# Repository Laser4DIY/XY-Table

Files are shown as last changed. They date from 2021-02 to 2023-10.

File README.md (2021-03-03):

# LASER4DIY Low Profile XY Table

XY table to be used for the Laser4DIY project, see http://www.laser4diy.org/

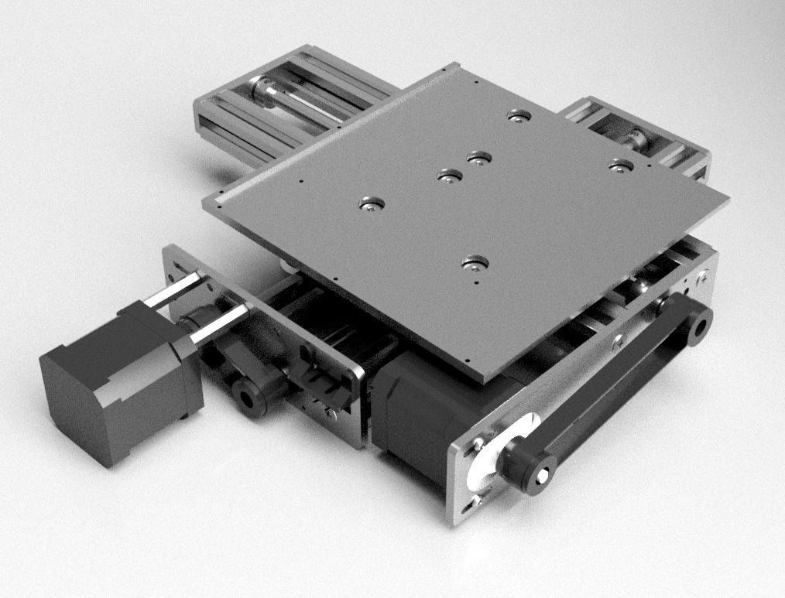
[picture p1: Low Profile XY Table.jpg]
Laser4DIY XY Table


- Table Size: 165mm x 165mm
- Overall Size: 368mm x 333mm x 56mm (with pancake motor)
- Based on 2 OpenBuilds NEMA17 V-Slot Actuators with Lead Screw

See https://wiki.fablab-muenchen.de/display/WIKI/LASER4DIY+Low+Profile+XY+Table for details.

--

Copyright FabLab München e.V. 2021

This source describes Open Hardware and is licensed under the CERN-OHL-P v2

You may redistribute and modify this documentation and make products using it 
under the terms of the CERN-OHL-P v2 (https:/cern.ch/cern-ohl).
This documentation is distributed WITHOUT ANY EXPRESS OR IMPLIED WARRANTY, 
INCLUDING OF MERCHANTABILITY, SATISFACTORY QUALITY AND FITNESS FOR A  PARTICULAR 
PURPOSE. Please see the CERN-OHL-P v2 for applicable conditions

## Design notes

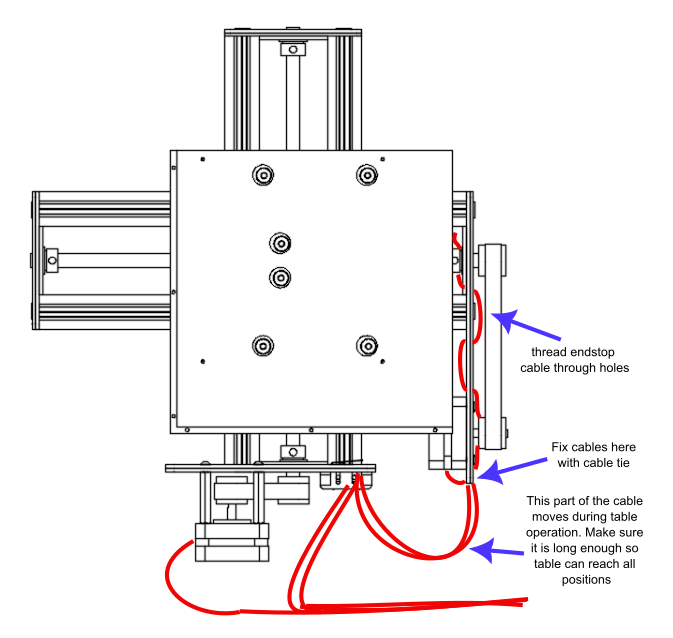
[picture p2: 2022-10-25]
documentation/drawing_cables.png

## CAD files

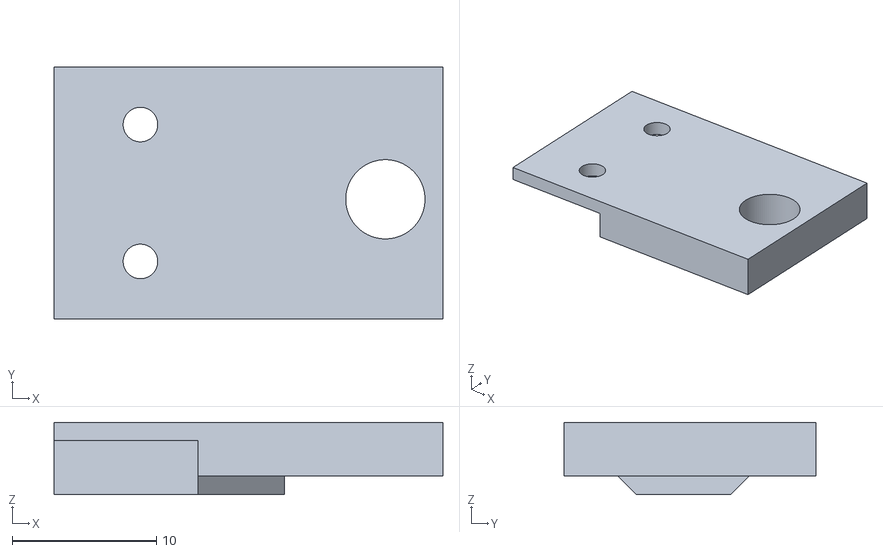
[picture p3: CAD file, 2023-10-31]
MicroswitchBracket2.stl
27.0 x 17.5 x 5.00

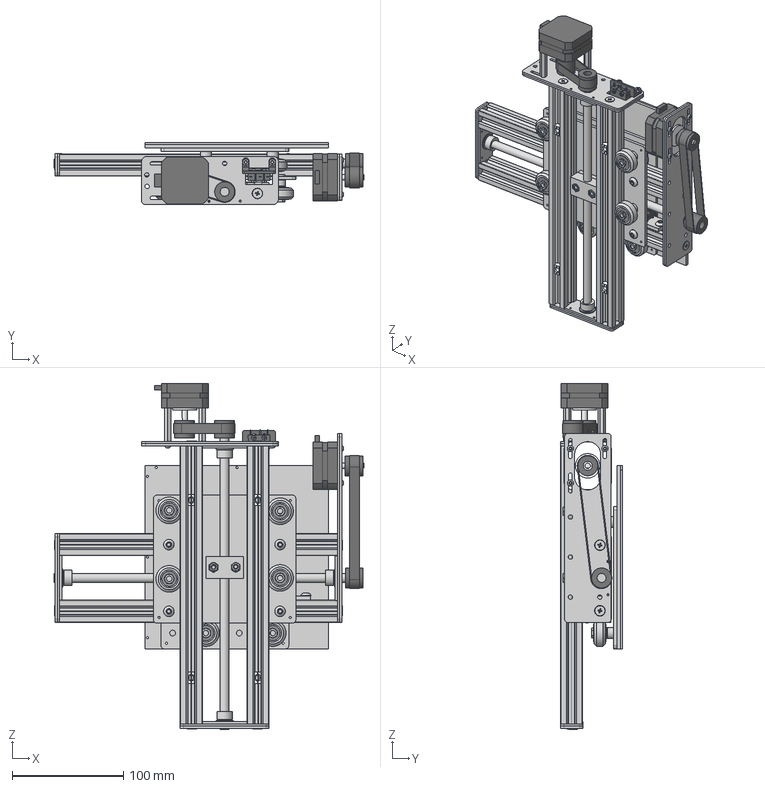
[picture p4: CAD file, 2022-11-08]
Low Profile XY Table.step
278.7 x 56.0 x 311.1 mm
Ball Bearing 8 x 16 x 5 (2) x 4
Lock Collar 8mm x 4
8mm leadscrew 270mm x 2
Self Tapping Screw x 8
Pulley 5mmID 18mmOD 16mmH x 3
Shim Wash 8mm x 4
V-Slot 20x20x250 x 4
StandardEndPlate_BeamBracket x 2
StandardEndPlate_InnerPart x 2
StandardEndPlate_OuterPart x 2
Solid V Wheel x 8
Ball Bearing 5 x 16 x 5 x 16
Precision Shim 10 x 5 x 1 x 16
Low Profile Nut M5 x 8
Aluminum Spacer 6mm x 8
8mm Acme Nut Block x 2
Low Profile Screw M5x20 x 4
Low Profile Screw M5x22 x 8
Nylon Insert Lock Nut M5 x 4
(3mm) SledPlate x 2
(5mm) SledSpacer x 2
Nema 17 Stepper Motor
belt2
Standoff M3 30mm x 3
Button Head Screw M3x8 x 8
Microswitch Panasonic AV32143AT x 2
Microswitch Bracket
EndPlateLower_BeamBracket
EndPlateLower_InnerPart
EndPlateLower_OuterPart
Button Head Screw M2x10 x 4
M2 Washer x 2
M2 nut x 4
M3 nut x 2
Nema 17 Stepper Motor (1)
belt1
Pulley 5mmID 18mmOD 16mmH (1)
Microswitch Bracket 2_1
EndPlateUpper_BeamBracket
EndPlateUpper_InnerPart
EndPlateUpper_OuterPart
T-Nut 2020 M5 v1 x 9
Button Head Screw M5x8 x 5
(3mm) BedPlate
(2mm) BedRuler

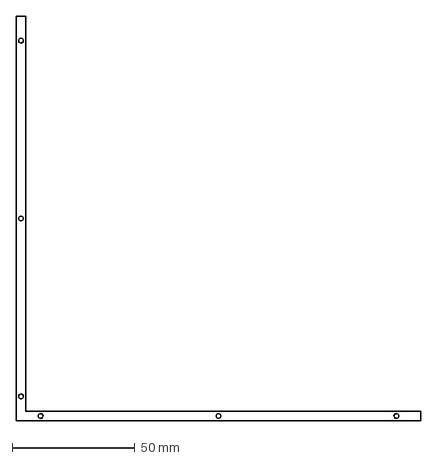
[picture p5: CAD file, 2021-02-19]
2mm_bedruler.dxf
165.0 x 165.0 mm

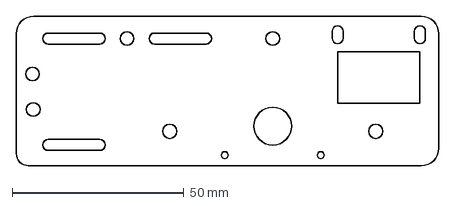
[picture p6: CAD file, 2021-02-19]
2mm_EndPlateLower_OuterPart.dxf
123.0 x 43.5 mm

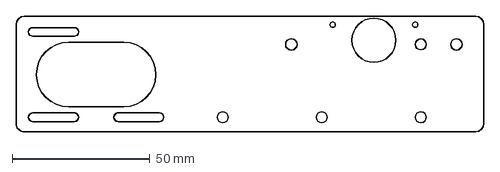
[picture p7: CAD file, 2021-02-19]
2mm_EndPlateUpper_InnerPart.dxf
170.0 x 41.9 mm

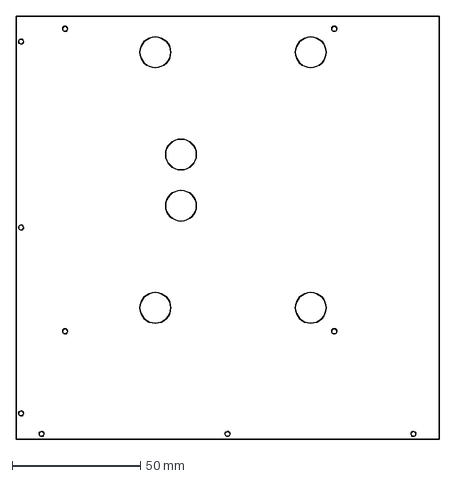
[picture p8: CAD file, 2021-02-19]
3mm_bedplate.dxf
165.0 x 165.0 mm

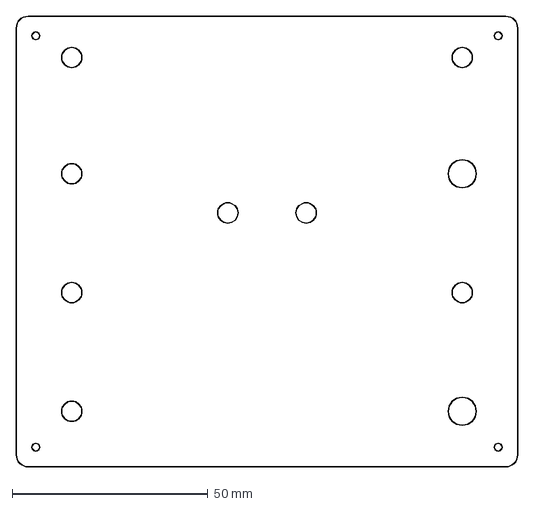
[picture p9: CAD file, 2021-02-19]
3mm_sledplate.dxf
128.0 x 115.0 mm

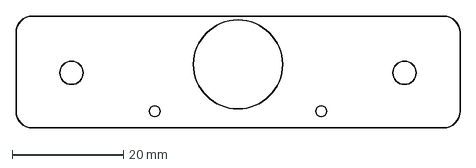
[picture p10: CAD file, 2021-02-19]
2mm_StandardEndPlate_InnerPart.dxf
80.0 x 20.1 mm

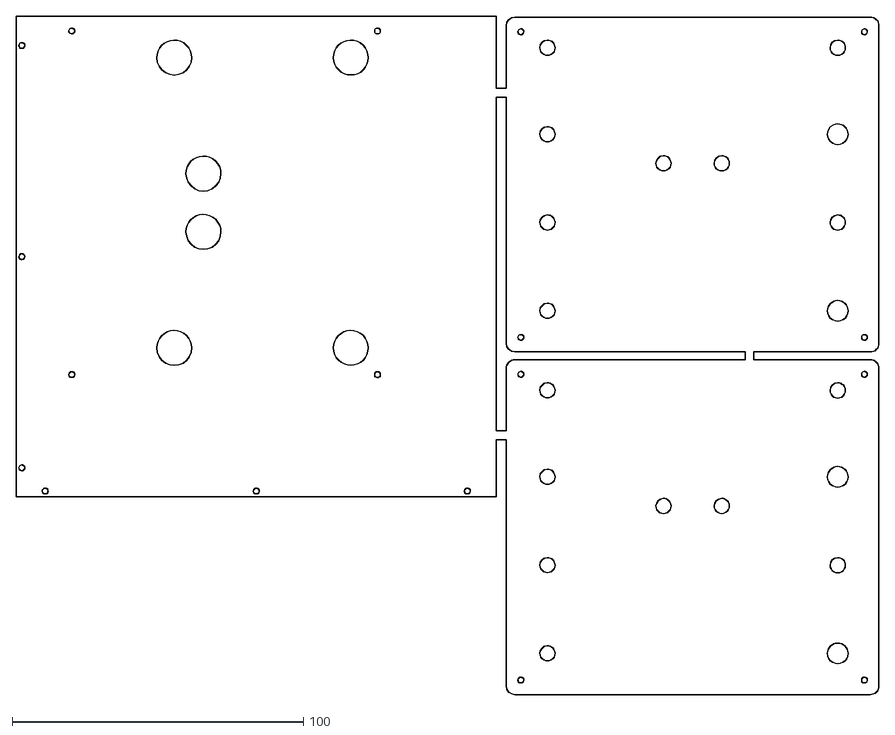
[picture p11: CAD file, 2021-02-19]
3mm_ALL_with_tabs.dxf
296.4 x 232.9

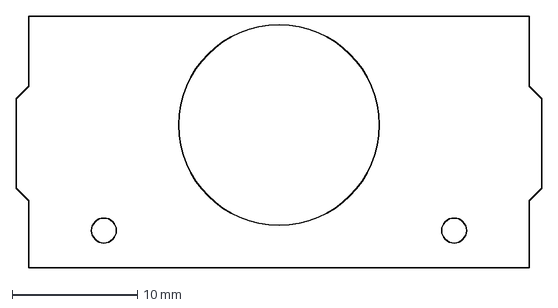
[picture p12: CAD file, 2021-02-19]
2mm_EndplateLower_BeamBracket.dxf
42.0 x 20.1 mm

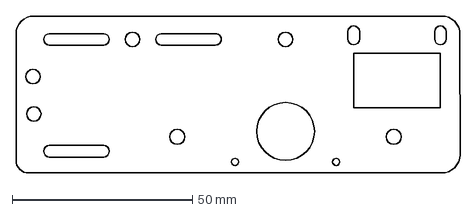
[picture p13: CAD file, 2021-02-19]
2mm_EndPlateLower_InnerPart.dxf
123.0 x 43.5 mm

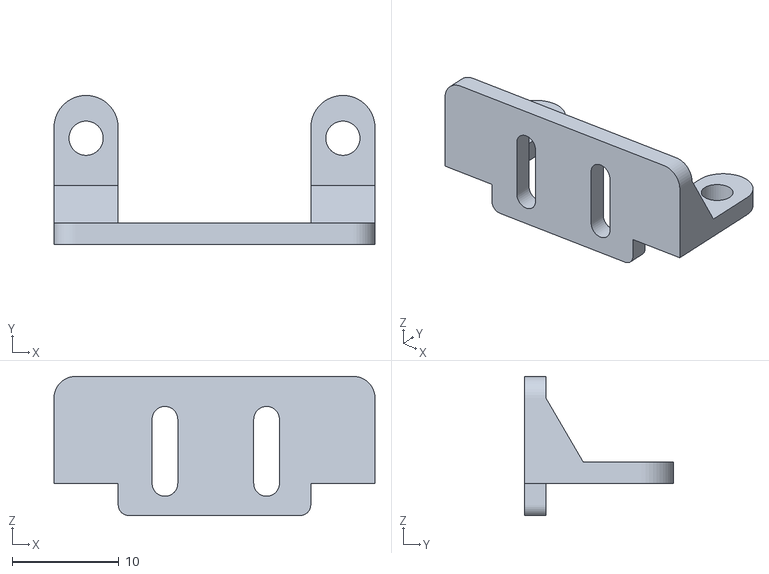
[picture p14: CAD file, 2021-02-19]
MicroswitchBracket.stl
30.0 x 13.9 x 13.0

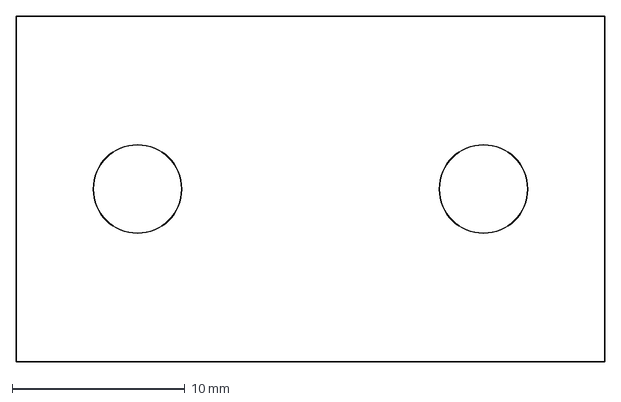
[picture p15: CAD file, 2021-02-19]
5mm_sledspacer.dxf
34.0 x 20.0 mm

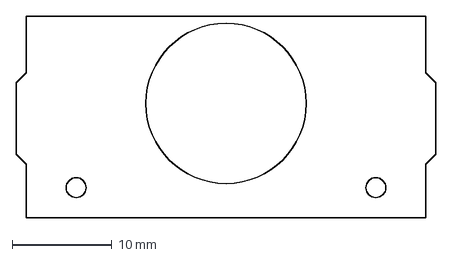
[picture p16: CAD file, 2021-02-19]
2mm_StandardEndPlate_BeamBracket.dxf
42.0 x 20.1 mm

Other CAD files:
2mm_EndPlateUpper_OuterPart.dxf
2mm_EndPlateUpper_BeamBracket.dxf
2mm_ALL_with_tabs.dxf
2mm_StandardEndPlate_OuterPart.dxf

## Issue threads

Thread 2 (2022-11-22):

Add pretension on lead screws

jankosso, 2022-11-22:
In the current setup it is hard to add pretension to the lead screw for eliminating axial play.

Currently I see two possible options here:
- Spring washer
Like DIN 137 Type B ("Federscheibe gewell"t), but thinner. I guess the DIN137 ones are too thick and need way too much force to bend.
- Pretention nut
https://openbuildspartstore.com/tension-nut/
https://makersupplies.dk/machine-components/transmission/acme-lead-screw/acme-lead-screw-nuts-tension-nut
Questions:
Is lead screw long enough?
Thrust bearing needed to support axial force on bearings?

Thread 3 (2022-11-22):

Not enough length on M5x22 low profile screw for V-groove wheels

jankosso, 2022-11-22:
The total length of the wheel assembly is too long and do not fit on the M5x22 low profile bolt.

3mm aluminium plate+ 6mm spacer + 1mm washer + 11mm whee results in only 1mm thread left for the nut:
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

Our solution was to remove the 1mm washer from assembly and change the sled spacer's height..
For us a spacer of 3,5mm (3mm PMMA, 0,5mm plastic from Nucleo board packaging) was optimal, 4mm was too thick.
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

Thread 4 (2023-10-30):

MicroswitchBracket2.stl cannot be mounted flat on aluminum profile

drayde, 2023-10-30:
MicroswitchBracket2.stl cannot be mounted flat on aluminum profile. The part that goes into the slot a bit goes too deep, it prevents the screw to be fully tightened

Closed 2023-10-31.

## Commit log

2021-02-19 iniital import
    [2mm_ALL_with_tabs.dxf, 2mm_EndPlateLower_InnerPart.dxf, 2mm_EndPlateLower_OuterPart.dxf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]
2022-10-25 added wiring diagram for documentation
2022-10-25 v37: added motor cable connectors
    [Low Profile XY Table.step]
2023-10-31 fixed issue #4 https://github.com/Laser4DIY/XY-Table/issues/4
    [MicroswitchBracket2.stl]
